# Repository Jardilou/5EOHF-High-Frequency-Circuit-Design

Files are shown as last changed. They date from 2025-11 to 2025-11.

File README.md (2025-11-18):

# 5EOHF-High-Frequency-Circuit-Design
The goal of this project is to create a pcb using an ESP32 microcontroller and able to send gps signals via LoRa communication. Two circuits will be fabricated separately, the first one for the microcontroller and the associated modules and the second one for the design of the antenna.

## 1. Project description
The components required for the main pcb assemply are listed in the BOM. Mainly, the modules are :
- GPS : SAM-M8Q-0
- ESP32 S3
- Lora Module RFM95 (868 MHz - without antenna, to be designed)
- Battery Power management 2S – BQ 25798
- USBC charging and programming pin
- SMA for custom antenna (868 MHz)

## 2. Schematic and Printed Circuit Board

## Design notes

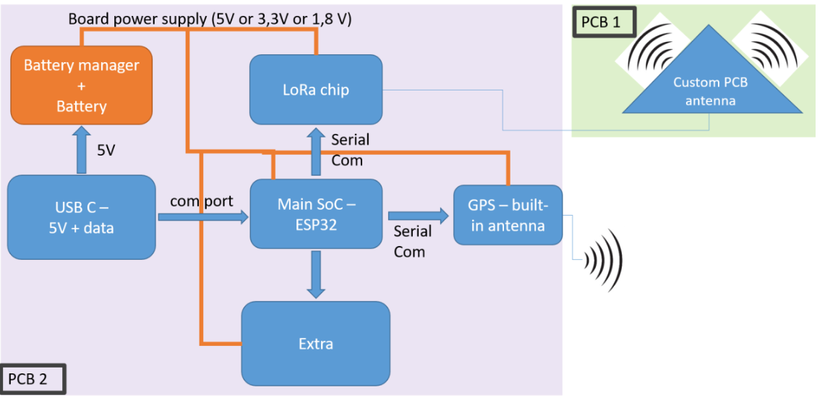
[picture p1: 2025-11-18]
Images/Block_Diagram.png

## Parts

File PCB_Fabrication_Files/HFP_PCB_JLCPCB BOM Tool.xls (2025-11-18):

JLCPCB BOM Tool - BOM Matching
BOM name：HFP_PCB-JLCPCB Assembly Order.xlsx |  |  |  | Download Time：2025-10-25 20:58:56 |  |  |  | * Our matching results are updated in real-time, but stock and prices may change. If it's been over 24 hours, please re-match before placing your order.
PCB Assembled Qty：2 |  |  |  | Est. Total Price：132.1933 (Pre-order parts require a quotation for final pricing.)
Your BOM |  |  |  | Matched Parts |  |  |  |  |  |  | Order Information
Designator | Comment | Footprint | JLCPCB Part # | Matches | Part # | Manufacturer | Footprint | Description | Category | Warning | JLCPCB Part # | Product link | Source | Lib Type | MOQ | Availability | My Parts(JLCPCB Parts) | My Parts(Global sourcing & consigned parts) | Rec. Order Qty | Unit Price ($) | Total Price ($)
680UF;C33;CP_ELEC_8X10 | 680UF;C33;CP_ELEC_8X10 | 680UF;C33;CP_ELEC_8X10 |  | Select by System | VMMD0790J681MV | Ymin | 680UF;C33;CP_ELEC_8X10 | 6.3V 680uF 7.9mm 8mm ±20% SMD,D8xL7.9mm Aluminum Electrolytic Capacitors - SMD ROHS | Aluminum Electrolytic Capacitors - SMD |  | C487009 | https://jlcpcb.com/partdetail/Ymin-VMMD0790J681MV/C487009 | In-stock | Extended | 1 | 8 | 0 | 0 | 2 | 0.2127 | 0.4254
10K;R24,R25,R16,R14;R_0201_0603METRIC | 10K;R24,R25,R16,R14;R_0201_0603METRIC | 10K;R24,R25,R16,R14;R_0201_0603METRIC |  | Unconfirmed | CR0201FH1002G | LIZ Elec | 10K;R24,R25,R16,R14;R_0201_0603METRIC | -55℃~+125℃ 10kΩ 25V 50mW Thick Film Resistor ±1% ±250ppm/℃ 0201 Chip Resistor - Surface Mount ROHS | Chip Resistor - Surface Mount | 1.There may be multiple types of parts, but one type of part has been matched. Please check.; | C100126 | https://jlcpcb.com/partdetail/LIZElec-CR0201FH1002G/C100126 | In-stock | Extended | 1 | 4355 | 0 | 0 | 20 | 0.0008 | 0.016
127K;R21;R_0201_0603METRIC | 127K;R21;R_0201_0603METRIC | 127K;R21;R_0201_0603METRIC |  | Select by System | RC0201FR-07127KL | YAGEO | 127K;R21;R_0201_0603METRIC | -55℃~+125℃ 127kΩ 25V 50mW Thick Film Resistor ±1% ±200ppm/℃ 0201 Chip Resistor - Surface Mount ROHS | Chip Resistor - Surface Mount |  | C138177 | https://jlcpcb.com/partdetail/YAGEO-RC0201FR07127KL/C138177 | In-stock | Extended | 1 | 2456 | 0 | 0 | 20 | 0.0005 | 0.01
6.04K;R20;R_0201_0603METRIC | 6.04K;R20;R_0201_0603METRIC | 6.04K;R20;R_0201_0603METRIC |  | Select by System | 0201WMF6041TEE | UNI-ROYAL(Uniroyal Elec) | 6.04K;R20;R_0201_0603METRIC | -55℃~+155℃ 25V 50mW 6.04kΩ Thick Film Resistor ±1% ±200ppm/℃ 0201 Chip Resistor - Surface Mount ROHS | Chip Resistor - Surface Mount |  | C270341 | https://jlcpcb.com/partdetail/259871-0201WMF6041TEE/C270341 | In-stock | Extended | 1 | 9077 | 0 | 0 | 20 | 0.0008 | 0.016
USB_C_RECEPTACLE_USB2.0_16P;J8;USB_C_RECEPTACLE_HRO_TYPE-C-31-M-12 | USB_C_RECEPTACLE_USB2.0_16P;J8;USB_C_RECEPTACLE_HRO_TYPE-C-31-M-12 | USB_C_RECEPTACLE_USB2.0_16P;J8;USB_C_RECEPTACLE_HRO_TYPE-C-31-M-12 |  | Select by System | TYPE-C-31-M-12 | Korean Hroparts Elec | USB_C_RECEPTACLE_USB2.0_16P;J8;USB_C_RECEPTACLE_HRO_TYPE-C-31-M-12 | 1 16P 5A Female Type-C SMD USB Connectors ROHS | USB Connectors |  | C165948 | https://jlcpcb.com/partdetail/Korean_HropartsElec-TYPE_C_31_M12/C165948 | In-stock | Extended | 1 | 337909 | 0 | 0 | 2 | 0.1694 | 0.3388
47NF;C29,C30;C_0603_1608METRIC | 47NF;C29,C30;C_0603_1608METRIC | 47NF;C29,C30;C_0603_1608METRIC |  | Unconfirmed | CL10B473KB8NNNC | Samsung Electro-Mechanics | 47NF;C29,C30;C_0603_1608METRIC | 47nF 50V X7R ±10% 0603 Multilayer Ceramic Capacitors MLCC - SMD/SMT ROHS | Multilayer Ceramic Capacitors MLCC - SMD/SMT | 1.There may be multiple types of parts, but one type of part has been matched. Please check.; | C1622 | https://jlcpcb.com/partdetail/1974-CL10B473KB8NNNC/C1622 | In-stock | Basic | 1 | 677018 | 0 | 0 | 20 | 0.0053 | 0.106
470;R26,R23;R_0201_0603METRIC | 470;R26,R23;R_0201_0603METRIC | 470;R26,R23;R_0201_0603METRIC |  | Unconfirmed | RTT014700FTH | RALEC | 470;R26,R23;R_0201_0603METRIC | -55℃~+125℃ 25V 470Ω 50mW Thick Film Resistor ±1% ±200ppm/℃ 0201 Chip Resistor - Surface Mount ROHS | Chip Resistor - Surface Mount | 1.There may be multiple types of parts, but one type of part has been matched. Please check.; | C166182 | https://jlcpcb.com/partdetail/RALEC-RTT014700FTH/C166182 | In-stock | Extended | 1 | 9899 | 0 | 0 | 20 | 0.0007 | 0.014
CONN_01X02_SOCKET;J7,J11,J9,J10;JST_EH_B2B-EH-A_1X02_P2.50MM_VERTICAL | CONN_01X02_SOCKET;J7,J11,J9,J10;JST_EH_B2B-EH-A_1X02_P2.50MM_VERTICAL | CONN_01X02_SOCKET;J7,J11,J9,J10;JST_EH_B2B-EH-A_1X02_P2.50MM_VERTICAL |  | Unconfirmed | B2B-EH-A(LF)(SN) | JST | CONN_01X02_SOCKET;J7,J11,J9,J10;JST_EH_B2B-EH-A_1X02_P2.50MM_VERTICAL | -25℃~+85℃ 1 1x2P 2 2.5mm 250V 2P 3.8mm 3A 6mm 7.5mm Brass EH PA66 Through Hole Tin UL94V-0 White Plugin,P=2.5mm Wire To Board Connector ROHS | Wire To Board Connector | 1.There may be multiple types of parts, but one type of part has been matched. Please check.; | C160262 | https://jlcpcb.com/partdetail/JST-B2B_EH_A_LF_SN/C160262 | In-stock | Extended | 1 | 16756 | 0 | 0 | 12 | 0.0377 | 0.4524
CONN_COAXIAL_SMALL;J12;BNC_TECONNECTIVITY_1478204_VERTICAL | CONN_COAXIAL_SMALL;J12;BNC_TECONNECTIVITY_1478204_VERTICAL | CONN_COAXIAL_SMALL;J12;BNC_TECONNECTIVITY_1478204_VERTICAL |  | Select by System | BNC-KF | cntitle | CONN_COAXIAL_SMALL;J12;BNC_TECONNECTIVITY_1478204_VERTICAL | - Coaxial Connectors (RF) ROHS | Coaxial Connectors (RF) |  | C20415781 | https://jlcpcb.com/partdetail/cntitle-BNCKF/C20415781 | In-stock | Extended | 1 | 89 | 0 | 0 | 2 | 1.47 | 2.94
1UH;L3;L_APV_ANR4018 | 1UH;L3;L_APV_ANR4018 | 1UH;L3;L_APV_ANR4018 |  | Select by System | PRS4018-1R0NT | FH (Guangdong Fenghua Advanced Tech) | 1UH;L3;L_APV_ANR4018 | 1uH 2A 39mΩ Magnetic Shielded Inductor ±30% SMD,4x4mm Power Inductors ROHS | Power Inductors |  | C96152 | https://jlcpcb.com/partdetail/97356-PRS40181R0NT/C96152 | In-stock | Extended | 1 | 180 | 0 | 0 | 6 | 0.0456 | 0.2736
0.1UF;C2,C35,C31,C32,C41;C_0402_1005METRIC | 0.1UF;C2,C35,C31,C32,C41;C_0402_1005METRIC | 0.1UF;C2,C35,C31,C32,C41;C_0402_1005METRIC |  | Unconfirmed | CL05B104KO5NNNC | Samsung Electro-Mechanics | 0.1UF;C2,C35,C31,C32,C41;C_0402_1005METRIC | 100nF 16V X7R ±10% 0402 Multilayer Ceramic Capacitors MLCC - SMD/SMT ROHS | Multilayer Ceramic Capacitors MLCC - SMD/SMT | 1.There may be multiple types of parts, but one type of part has been matched. Please check.; | C1525 | https://jlcpcb.com/partdetail/1877-CL05B104KO5NNNC/C1525 | In-stock | Basic | 1 | 16856069 | 0 | 0 | 20 | 0.0012 | 0.024
5K1;R17,R18;R_0201_0603METRIC | 5K1;R17,R18;R_0201_0603METRIC | 5K1;R17,R18;R_0201_0603METRIC |  | Unconfirmed | CR0201FH5101G | LIZ Elec | 5K1;R17,R18;R_0201_0603METRIC | -55℃~+125℃ 25V 5.1kΩ 50mW Thick Film Resistor ±1% ±250ppm/℃ 0201 Chip Resistor - Surface Mount ROHS | Chip Resistor - Surface Mount | 1.There may be multiple types of parts, but one type of part has been matched. Please check.; | C100142 | https://jlcpcb.com/partdetail/LIZElec-CR0201FH5101G/C100142 | In-stock | Extended | 1 | 2062 | 0 | 0 | 20 | 0.0007 | 0.014
10UF;C34,C45,C50,C44,C42,C43,C46,C49,C39,C37,C48,C40,C47,C51;C_1206_3216METRIC | 10UF;C34,C45,C50,C44,C42,C43,C46,C49,C39,C37,C48,C40,C47,C51;C_1206_3216METRIC | 10UF;C34,C45,C50,C44,C42,C43,C46,C49,C39,C37,C48,C40,C47,C51;C_1206_3216METRIC |  | Unconfirmed | CL31A106KOHNNNE | Samsung Electro-Mechanics | 10UF;C34,C45,C50,C44,C42,C43,C46,C49,C39,C37,C48,C40,C47,C51;C_1206_3216METRIC | 10uF 16V X5R ±10% 1206 Multilayer Ceramic Capacitors MLCC - SMD/SMT ROHS | Multilayer Ceramic Capacitors MLCC - SMD/SMT | 1.There may be multiple types of parts, but one type of part has been matched. Please check.; | C1849 | https://jlcpcb.com/partdetail/2201-CL31A106KOHNNNE/C1849 | In-stock | Extended | 1 | 143159 | 0 | 0 | 36 | 0.0272 | 0.9792
100;R19;R_0201_0603METRIC | 100;R19;R_0201_0603METRIC | 100;R19;R_0201_0603METRIC |  | Select by System | RC0201FR-07100RL | YAGEO | 100;R19;R_0201_0603METRIC | -55℃~+125℃ 100Ω 25V 50mW Thick Film Resistor ±1% ±200ppm/℃ 0201 Chip Resistor - Surface Mount ROHS | Chip Resistor - Surface Mount |  | C77623 | https://jlcpcb.com/partdetail/YAGEO-RC0201FR07100RL/C77623 | In-stock | Extended | 1 | 133970 | 0 | 0 | 20 | 0.0008 | 0.016
33UH;L4;L_APV_ANR8040 | 33UH;L4;L_APV_ANR8040 | 33UH;L4;L_APV_ANR8040 |  | Select by System | FNR8040S330MT | cjiang (Changjiang Microelectronics Tech) | 33UH;L4;L_APV_ANR8040 | 126mΩ 2.4A 2A 33uH Magnetic Shielded Inductor ±20% SMD,8x8mm Power Inductors ROHS | Power Inductors |  | C168133 | https://jlcpcb.com/partdetail/179516-FNR8040S330MT/C168133 | In-stock | Extended | 1 | 6888 | 0 | 0 | 5 | 0.1023 | 0.5115
1NF;C36;C_0402_1005METRIC | 1NF;C36;C_0402_1005METRIC | 1NF;C36;C_0402_1005METRIC |  | Select by System | 0402B102K500NT | FH (Guangdong Fenghua Advanced Tech) | 1NF;C36;C_0402_1005METRIC | 1nF 50V X7R ±10% 0402 Multilayer Ceramic Capacitors MLCC - SMD/SMT ROHS | Multilayer Ceramic Capacitors MLCC - SMD/SMT |  | C1523 | https://jlcpcb.com/partdetail/1875-0402B102K500NT/C1523 | In-stock | Basic | 1 | 1460783 | 0 | 0 | 20 | 0.0011 | 0.022
LM2596S-3.3;U9;TO-263-5_TABPIN3 | LM2596S-3.3;U9;TO-263-5_TABPIN3 | LM2596S-3.3;U9;TO-263-5_TABPIN3 |  | Select by System | LM2596S-3.3 | GR | LM2596S-3.3;U9;TO-263-5_TABPIN3 | -20℃~+70℃ 1 170kHz 2mA 3.3V 3A 4.5V~40V Buck Buck Built-In Fixed No TO-263-5L DC-DC Converters ROHS | DC-DC Converters |  | C19631822 | https://jlcpcb.com/partdetail/GR-LM2596S_33/C19631822 | In-stock | Extended | 1 | 4577 | 0 | 0 | 2 | 0.252 | 0.504
100K;R22;R_0201_0603METRIC | 100K;R22;R_0201_0603METRIC | 100K;R22;R_0201_0603METRIC |  | Select by System | CR0201FH1003G | LIZ Elec | 100K;R22;R_0201_0603METRIC | -55℃~+125℃ 100kΩ 25V 50mW Thick Film Resistor ±1% ±250ppm/℃ 0201 Chip Resistor - Surface Mount ROHS | Chip Resistor - Surface Mount |  | C100127 | https://jlcpcb.com/partdetail/LIZElec-CR0201FH1003G/C100127 | In-stock | Extended | 1 | 7239 | 0 | 0 | 20 | 0.0008 | 0.016
AMS1117-3.3;U10;SOT-223-3_TABPIN2 | AMS1117-3.3;U10;SOT-223-3_TABPIN2 | AMS1117-3.3;U10;SOT-223-3_TABPIN2 |  | Unconfirmed | AMS1117-3.3 | Advanced Monolithic Systems | AMS1117-3.3;U10;SOT-223-3_TABPIN2 | -40℃~+125℃ 0.003%Vout 1 1.1V@(800mA) 16V 1A 3.3V 5mA 72dB@(120Hz) Fixed Over Current Protection Positive SOT-223 Voltage Regulators - Linear, Low Drop Out (LDO) Regulators ROHS | Voltage Regulators - Linear, Low Drop Out (LDO) Regulators | 1.The comment (AMS1117-3.3) of this part does not match the one (AMS1117-3.3;U10;SOT-223-3_TABPIN2) provided in your BOM. Please confirm; | C6186 | https://jlcpcb.com/partdetail/Advanced_MonolithicSystems-AMS1117_33/C6186 | In-stock | Basic | 1 | 1320981 | 0 | 0 | 2 | 0.1639 | 0.3278
1N5820;D2;D_DO-201AD_P15.24MM_HORIZONTAL | 1N5820;D2;D_DO-201AD_P15.24MM_HORIZONTAL | 1N5820;D2;D_DO-201AD_P15.24MM_HORIZONTAL |  | Select by Customer | 1N5820RLG | onsemi | 1N5820;D2;D_DO-201AD_P15.24MM_HORIZONTAL | 20V 2mA@20V 3A 850mV@9.3A DO-201AD Schottky Diodes ROHS | Schottky Diodes |  | C900156 | https://jlcpcb.com/partdetail/onsemi-1N5820RLG/C900156 | Pre-order | Extended | 25 | 0 | 0 | 0 | 25 | 0.3515 | 8.7875
BQ25798RQMR;U8;IC_BQ25798RQMR | BQ25798RQMR;U8;IC_BQ25798RQMR | BQ25798RQMR;U8;IC_BQ25798RQMR |  | Select by System | BQ25798RQMR | Texas Instruments | BQ25798RQMR;U8;IC_BQ25798RQMR | -40℃~+85℃ 17uA 1~4 3.6V~24V 5A Charging IC I2C Lithium Battery Support QFN-29(4x4) Battery Management ROHS | Battery Management |  | C2876593 | https://jlcpcb.com/partdetail/TexasInstruments-BQ25798RQMR/C2876593 | Pre-order | Extended | 4 | 0 | 0 | 0 | 4 | 2.2725 | 9.09
1M;R15;R_0201_0603METRIC | 1M;R15;R_0201_0603METRIC | 1M;R15;R_0201_0603METRIC |  | Select by System | CR0201FH1004G | LIZ Elec | 1M;R15;R_0201_0603METRIC | -55℃~+125℃ 1MΩ 25V 50mW Thick Film Resistor ±1% ±250ppm/℃ 0201 Chip Resistor - Surface Mount ROHS | Chip Resistor - Surface Mount |  | C100128 | https://jlcpcb.com/partdetail/LIZElec-CR0201FH1004G/C100128 | Pre-order | Extended | 10000 | 5 | 0 | 0 | 10000 | 0.0006 | 6
4.7UF;C38;C_0805_2012METRIC | 4.7UF;C38;C_0805_2012METRIC | 4.7UF;C38;C_0805_2012METRIC |  | Select by System | C0805C475K3PAC7800 | KEMET | 4.7UF;C38;C_0805_2012METRIC | 25V 4.7uF X5R ±10% 0805 Multilayer Ceramic Capacitors MLCC - SMD/SMT ROHS | Multilayer Ceramic Capacitors MLCC - SMD/SMT |  | C141036 | https://jlcpcb.com/partdetail/KEMET-C0805C475K3PAC7800/C141036 | Pre-order | Extended | 165 | 0 | 0 | 0 | 165 | 0.0521 | 8.5965
RFM95W-868S2;U13;HOPERF_RFM9XW_SMD | RFM95W-868S2;U13;HOPERF_RFM9XW_SMD | RFM95W-868S2;U13;HOPERF_RFM9XW_SMD |  | Select by System | RFM95W-868S2R | HOPE MICROELECTRONICS | RFM95W-868S2;U13;HOPERF_RFM9XW_SMD | LCC-16_16X16X2.0P New Arrivals ROHS | New Arrivals |  | C5440766 | https://jlcpcb.com/partdetail/HOPEMICROELECTRONICS-RFM95W868S2R/C5440766 | Pre-order | Extended | 456 | 0 | 0 | 0 | 456 | 0.0188 | 8.5728
ESP32-S3-WROOM-2;U2;ESP32-S3-WROOM-2 | ESP32-S3-WROOM-2;U2;ESP32-S3-WROOM-2 | ESP32-S3-WROOM-2;U2;ESP32-S3-WROOM-2 |  | Select by System | ESP32-S3-WROOM-2-N32R8V | JLCPCB Assembly | ESP32-S3-WROOM-2;U2;ESP32-S3-WROOM-2 | LCC+LGA SMT ROHS | SMT |  | C9900017856 | https://jlcpcb.com/partdetail/3524184-ESP32_S3_WROOM_2N32R8V/C9900017856 | Pre-order | Extended | 456 | 0 | 0 | 0 | 456 | 0.0188 | 8.5728
SAM-M8Q;U11;UBLOX_SAM-M8Q | SAM-M8Q;U11;UBLOX_SAM-M8Q | SAM-M8Q;U11;UBLOX_SAM-M8Q |  | Select by System | SAM-M8Q-0 | U-BLOX | SAM-M8Q;U11;UBLOX_SAM-M8Q | SMD-20P,15x15mm GNSS Modules ROHS | GNSS Modules |  | C5447387 | https://jlcpcb.com/partdetail/UBLOX-SAM_M8Q0/C5447387 | Pre-order | Extended | 1 | 0 | 0 | 0 | 2 | 37.7835 | 75.567
ESP32-S3-DEVKITC-1-N8R2;U14;XCVR_ESP32-S3-DEVKITC-1-N8R2 | ESP32-S3-DEVKITC-1-N8R2;U14;XCVR_ESP32-S3-DEVKITC-1-N8R2 | ESP32-S3-DEVKITC-1-N8R2;U14;XCVR_ESP32-S3-DEVKITC-1-N8R2 |  | No matches |  | No Part Selected
TESTPOINT;TP20,TP26,TP16,TP28,TP23,TP22,TP19,TP29,TP30,TP27,TP25,TP17,TP24,TP18,TP21;TESTPOINT_KEYSTONE_5005-5009_COMPACT | TESTPOINT;TP20,TP26,TP16,TP28,TP23,TP22,TP19,TP29,TP30,TP27,TP25,TP17,TP24,TP18,TP21;TESTPOINT_KEYSTONE_5005-5009_COMPACT | TESTPOINT;TP20,TP26,TP16,TP28,TP23,TP22,TP19,TP29,TP30,TP27,TP25,TP17,TP24,TP18,TP21;TESTPOINT_KEYSTONE_5005-5009_COMPACT |  | No matches |  | No Part Selected
COMMENT;DESIGNATOR;FOOTPRINT | COMMENT;DESIGNATOR;FOOTPRINT | COMMENT;DESIGNATOR;FOOTPRINT |  | No matches |  | No Part Selected

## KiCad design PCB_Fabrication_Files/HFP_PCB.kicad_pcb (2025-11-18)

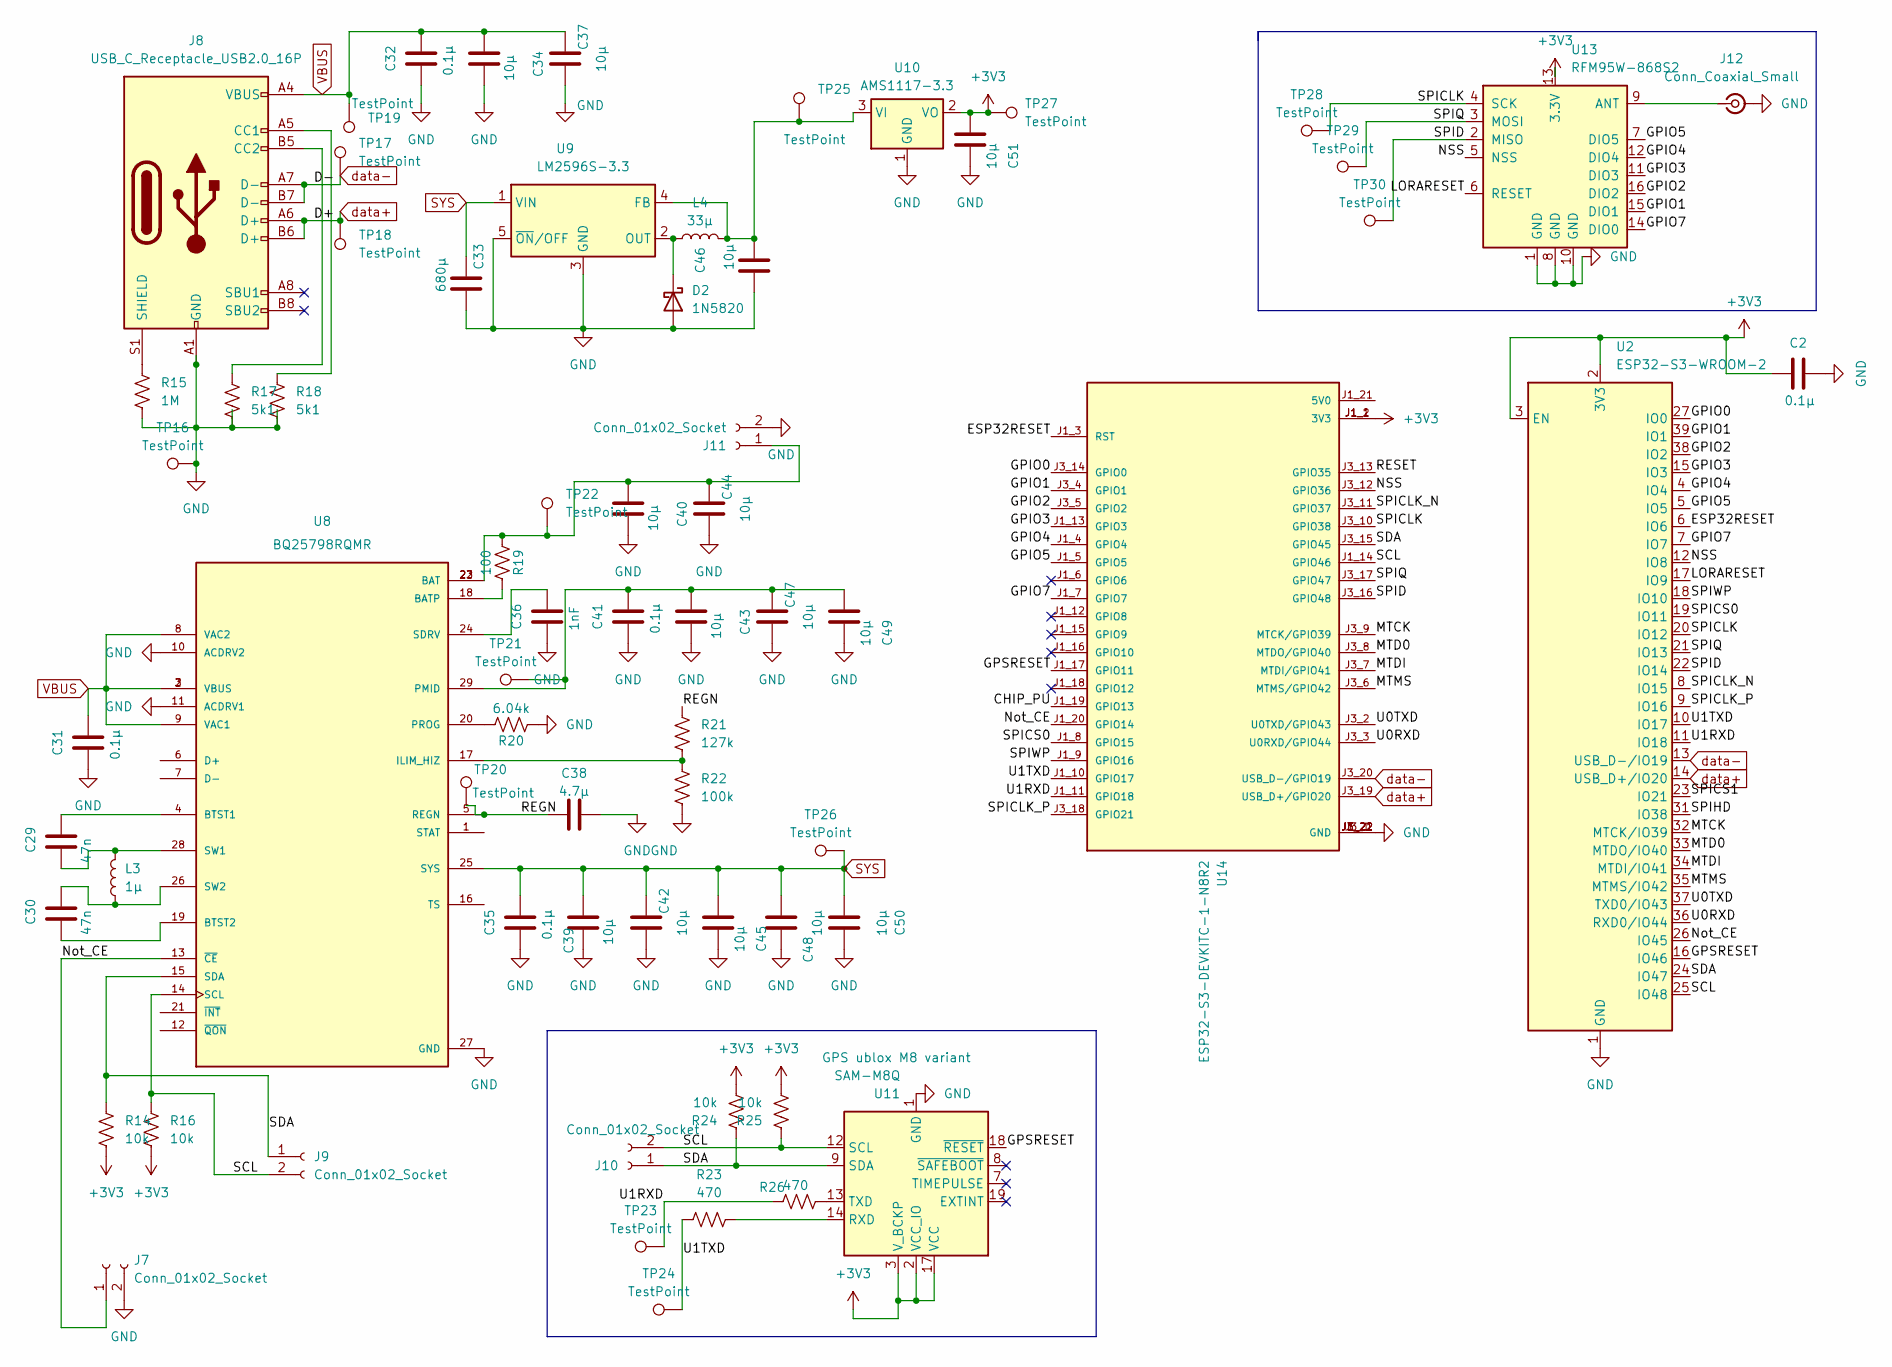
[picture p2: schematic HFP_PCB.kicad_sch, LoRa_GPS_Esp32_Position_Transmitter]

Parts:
C2, C31, C32, C35, C41: 0.1µ; C_0402_1005Metric
C29, C30: 47n; C_0603_1608Metric
C33: 680µ; CP_Elec_8x10
C34, C37, C39, C40, C42, C43, C44, C45, C46, C47, C48, C49, C50, C51: 10µ; C_1206_3216Metric
C36: 1nF; C_0402_1005Metric
C38: 4.7µ; C_0805_2012Metric
D2: 1N5820; D_DO-201AD_P15.24mm_Horizontal
J7, J9, J10, J11: Conn_01x02_Socket; JST_EH_B2B-EH-A_1x02_P2.50mm_Vertical
J8: USB_C_Receptacle_USB2.0_16P; USB_C_Receptacle_HRO_TYPE-C-31-M-12
J12: Conn_Coaxial_Small; BNC_TEConnectivity_1478204_Vertical
L3: 1µ; L_APV_ANR4018
L4: 33µ; L_APV_ANR8040
R14, R16, R24, R25: 10k; R_0201_0603Metric
R15: 1M; R_0201_0603Metric
R17, R18: 5k1; R_0201_0603Metric
R19: 100; R_0201_0603Metric
R20: 6.04k; R_0201_0603Metric
R21: 127k; R_0201_0603Metric
R22: 100k; R_0201_0603Metric
R23, R26: 470; R_0201_0603Metric
TP16, TP17, TP18, TP19, TP20, TP21, TP22, TP23, TP24, TP25, TP26, TP27, TP28, TP29, TP30: TestPoint; TestPoint_Keystone_5005-5009_Compact
U2: ESP32-S3-WROOM-2
U8: BQ25798RQMR; IC_BQ25798RQMR; PARTREV B
U9: LM2596S-3.3; TO-263-5_TabPin3
U10: AMS1117-3.3; SOT-223-3_TabPin2
U11: SAM-M8Q; ublox_SAM-M8Q
U13: RFM95W-868S2; HOPERF_RFM9XW_SMD
U14: ESP32-S3-DEVKITC-1-N8R2; XCVR_ESP32-S3-DEVKITC-1-N8R2; PARTREV V1

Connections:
+3V3: C2.1, C51.1, R14.1, R16.1, R24.1, R25.1, TP27.1, U2.2 (3V3), U2.3 (EN), U10.2 (VO), U11.2 (VCC_IO), U11.3 (V_BCKP), U11.17 (VCC), U13.13 (3.3V), U14.J1_1 (3V3), U14.J1_2 (3V3)
/CHIP_PU: U14.J1_19 (GPIO13)
/ESP32RESET: U2.6 (IO6), U14.J1_3 (RST)
/GPIO0: U2.27 (IO0), U14.J3_14 (GPIO0)
/GPIO1: U2.39 (IO1), U13.15 (DIO1), U14.J3_4 (GPIO1)
/GPIO2: U2.38 (IO2), U13.16 (DIO2), U14.J3_5 (GPIO2)
/GPIO3: U2.15 (IO3), U13.11 (DIO3), U14.J1_13 (GPIO3)
/GPIO4: U2.4 (IO4), U13.12 (DIO4), U14.J1_4 (GPIO4)
/GPIO5: U2.5 (IO5), U13.7 (DIO5), U14.J1_5 (GPIO5)
/GPIO7: U2.7 (IO7), U13.14 (DIO0), U14.J1_7 (GPIO7)
/GPSRESET: U2.16 (IO46), U11.18 (~RESET), U14.J1_17 (GPIO11)
/LORARESET: U2.17 (IO9), U13.6 (RESET)
/MTCK: U2.32 (MTCK/IO39), U14.J3_9 (MTCK/GPIO39)
/MTD0: U2.33 (MTDO/IO40), U14.J3_8 (MTDO/GPIO40)
/MTDI: U2.34 (MTDI/IO41), U14.J3_7 (MTDI/GPIO41)
/MTMS: U2.35 (MTMS/IO42), U14.J3_6 (MTMS/GPIO42)
/NSS: U2.12 (IO8), U13.5 (NSS), U14.J3_12 (GPIO36)
/Not_CE: J7.1, U2.26 (IO45), U8.13 (~CE), U14.J1_20 (GPIO14)
/REGN: C38.1, R21.1, TP20.1, U8.5 (REGN)
/RESET: U14.J3_13 (GPIO35)
/SCL: J9.2, J10.2, R16.2, R25.2, U2.25 (IO48), U8.14 (SCL), U11.12 (SCL), U14.J1_14 (GPIO46)
/SDA: J9.1, J10.1, R14.2, R24.2, U2.24 (IO47), U8.15 (SDA), U11.9 (SDA), U14.J3_15 (GPIO45)
/SPICLK: TP28.1, U2.20 (IO12), U13.4 (SCK), U14.J3_10 (GPIO38)
/SPICLK_N: U2.8 (IO15), U14.J3_11 (GPIO37)
/SPICLK_P: U2.9 (IO16), U14.J3_18 (GPIO21)
/SPICS0: U2.19 (IO11), U14.J1_8 (GPIO15)
/SPICS1: U2.23 (IO21)
/SPID: TP30.1, U2.22 (IO14), U13.2 (MISO), U14.J3_16 (GPIO48)
/SPIHD: U2.31 (IO38)
/SPIQ: TP29.1, U2.21 (IO13), U13.3 (MOSI), U14.J3_17 (GPIO47)
/SPIWP: U2.18 (IO10), U14.J1_9 (GPIO16)
/U0RXD: U2.36 (RXD0/IO44), U14.J3_3 (U0RXD/GPIO44)
/U0TXD: U2.37 (TXD0/IO43), U14.J3_2 (U0TXD/GPIO43)
/U1RXD: R26.1, TP23.1, U2.11 (IO18), U14.J1_11 (GPIO18)
/U1TXD: R23.1, TP24.1, U2.10 (IO17), U14.J1_10 (GPIO17)
GND: C2.2, C31.2, C32.2, C33.1, C34.2, C35.2, C36.2, C37.2, C38.2, C39.2, C40.2, C41.2, C42.2, C43.2, C44.2, C45.2, C46.1, C47.2, C48.2, C49.2, C50.2, C51.2, D2.2 (A), J7.2, J8.A1 (GND), J8.A12 (GND), J8.B1 (GND), J8.B12 (GND), J11.2, J12.2 (Ext), R15.1, R17.1, R18.1, R20.1, R22.2, TP16.1, U2.1 (GND), U2.40 (GND), U2.41 (GND), U8.10 (ACDRV2), U8.11 (ACDRV1), U8.27 (GND), U9.3 (GND), U9.5 (~ON/OFF), U10.1 (GND), U11.1 (GND), U11.4 (GND), U11.5 (GND), U11.6 (GND), U11.10 (GND), U11.11 (GND), U11.15 (GND), U11.16 (GND), U11.20 (GND), U13.1 (GND), U13.8 (GND), U13.10 (GND), U14.J1_22 (GND), U14.J3_1 (GND), U14.J3_21 (GND), U14.J3_22 (GND)
unnamed: D2.1 (K), L4.1, U9.2 (OUT)
unnamed: J8.A5 (CC1), R18.2
unnamed: J8.B5 (CC2), R17.2
unnamed: J8.S1 (SHIELD), R15.2
unnamed: C40.1, C44.1, J11.1, R19.1, TP22.1, U8.22 (BAT), U8.23 (BAT)
unnamed: J12.1 (In), U13.9 (ANT)
unnamed: R19.2, U8.18 (BATP)
unnamed: C29.1, U8.4 (BTST1)
unnamed: C30.2, U8.19 (BTST2)
unnamed: R21.2, R22.1, U8.17 (ILIM_HIZ)
unnamed: C41.1, C43.1, C47.1, C49.1, TP21.1, U8.29 (PMID)
unnamed: R20.2, U8.20 (PROG)
unnamed: C36.1, U8.24 (SDRV)
unnamed: C29.2, L3.2, U8.28 (SW1)
unnamed: C30.1, L3.1, U8.26 (SW2)
unnamed: C46.2, L4.2, TP25.1, U9.4 (FB), U10.3 (VI)
unnamed: R23.2, U11.14 (RXD)
unnamed: R26.2, U11.13 (TXD)
SYS: C33.2, C35.1, C39.1, C42.1, C45.1, C48.1, C50.1, TP26.1, U8.25 (SYS), U9.1 (VIN)
VBUS: C31.1, C32.1, C34.1, C37.1, J8.A4 (VBUS), J8.A9 (VBUS), J8.B4 (VBUS), J8.B9 (VBUS), TP19.1, U8.2 (VBUS), U8.3 (VBUS), U8.8 (VAC2), U8.9 (VAC1)
data+: J8.A6 (D+), J8.B6 (D+), TP18.1, U2.14 (USB_D+/IO20), U14.J3_19 (USB_D+/GPIO20)
data-: J8.A7 (D-), J8.B7 (D-), TP17.1, U2.13 (USB_D-/IO19), U14.J3_20 (USB_D-/GPIO19)

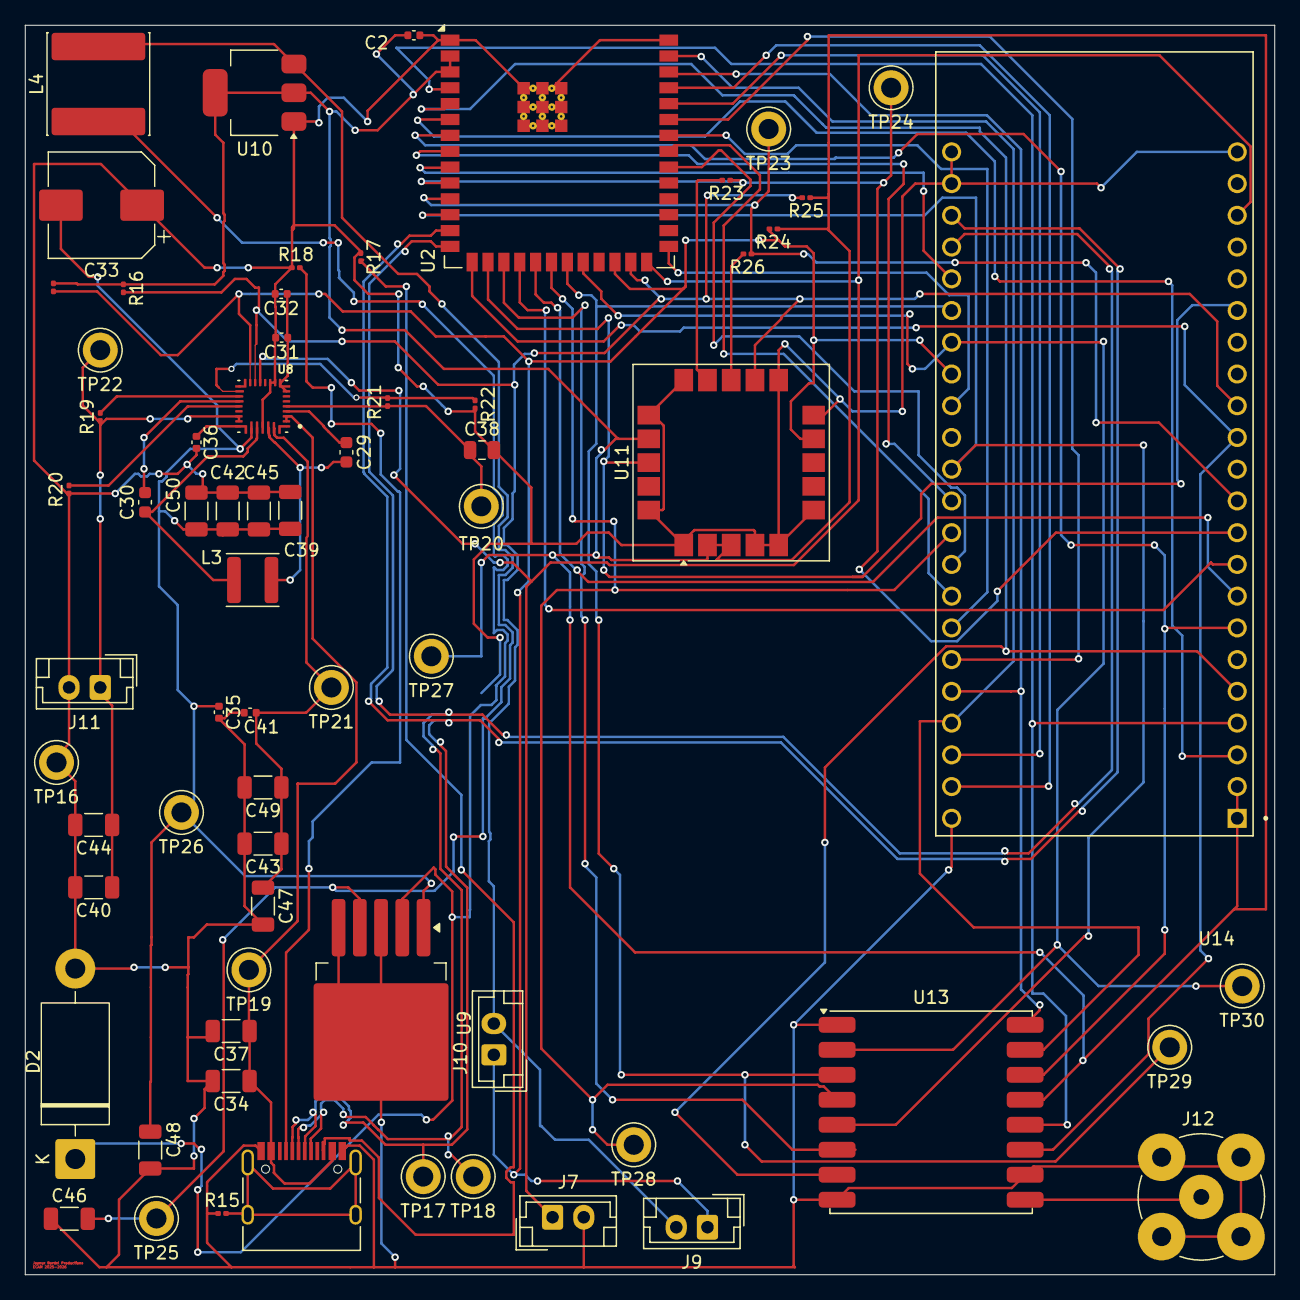
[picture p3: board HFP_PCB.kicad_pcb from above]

Board: 2 copper layers, 100.0 x 100.0 mm, 68 parts (1 on the bottom side), 54 nets.

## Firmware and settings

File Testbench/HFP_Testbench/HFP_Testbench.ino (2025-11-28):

/* 
  ESP32 Unit Test Suite
  - ESP32 basic checks: boot, GPIO toggle
  - WiFi: scan and simple TCP ping attempt (scan only; no credentials)
  - BLE: advertise + passive scan
  - SAM-M8Q: UART NMEA reader + I2C presence probe (addr 0x42)
  - RFM95: SPI RegVersion read, Reset cycle, optional LoRa transmit (if "LoRa" library is installed)
  - Serial output at 115200 for results
  IMPORTANT: Many ESP32 boards reserve GPIO6..GPIO11 for flash/PSRAM. Using GPIO6/GPIO7 may break the module.
  We should adjust pins if we encounter boot issues!
*/

#include <Arduino.h>
#include <Wire.h>
#include <WiFi.h>
#include <BLEDevice.h>
#include <BLEUtils.h>
#include <BLEServer.h>
#include <SPI.h>

// Optional LoRa library: uncomment if you have the Sandeep Mistry LoRa library installed
// #include <LoRa.h>

///// USER PIN CONFIG (from your message) /////
const int PIN_RFM95_SCK  = 33; // SCK
const int PIN_RFM95_SPIQ = 34; // SPIQ (may be DIO/IRQ depending on your board)
const int PIN_RFM95_SPID = 35; // SPID (MISO/MOSI naming ambiguous; treat as MISO here)
const int PIN_RFM95_NSS  = 6;  // NSS (WARNING: GPIO6 is sometimes reserved for flash)
const int PIN_RFM95_RESET= 7;  // RESET (WARNING: GPIO7 may be reserved)
const int PIN_RFM95_DIO0 = PIN_RFM95_SPIQ; // fallback: if SPIQ is DIO0/IRQ, used for LoRa library

const int GPS_UART_TX = 17; // U1TXD (ESP32 -> GPS)
const int GPS_UART_RX = 18; // U1RXD (GPS -> ESP32)
const int GPS_I2C_SDA = 51; // GPIO45
const int GPS_I2C_SCL = 52; // GPIO46
const uint8_t GPS_I2C_ADDR = 0x42; // typical UBX I2C address (0x42)

const int LED_TEST_PIN = 2; // on-board LED or any test pin
const int GPIO_TEST_PINS[] = {2, 4, 12}; // extra pins toggled during GPIO test
const size_t N_GPIO_TEST_PINS = sizeof(GPIO_TEST_PINS)/sizeof(GPIO_TEST_PINS[0]);

HardwareSerial GPSu(1); // use UART1 for GPS (pins 17 TX, 18 RX)

SPIClass hspi(HSPI); // we'll bind HSPI to custom pins

// Helper timing
unsigned long nowMs() { return millis(); }

/////////////////////////
// Test helpers
/////////////////////////

void printHeader(const char* title) {
  Serial.println();
  Serial.print("=== ");
  Serial.print(title);
  Serial.println(" ===");
}

void pauseMs(unsigned long ms) {
  unsigned long t = nowMs();
  while (nowMs() - t < ms) { yield(); }
}

/////////////////////////
// ESP32: power/boot / basic tests
/////////////////////////

void test_boot_and_power() {
  printHeader("ESP32 Boot & Power Test");
  Serial.printf("Boot time millis: %lu\n", nowMs());
  // Basic sanity: check Vcc reading (if ADC on board measures it) - optional
  Serial.println("Note: measure 3.3V rail externally with DVM/oscilloscope under load for full power test.");
  Serial.println("Result: BOOT OK (if you see this message and no brownout resets).");
}

void test_gpio() {
  printHeader("GPIO Digital IO Test");
  Serial.println("Toggling GPIO test pins and reading them back where possible.");
  for (size_t i = 0; i < N_GPIO_TEST_PINS; ++i) {
    int p = GPIO_TEST_PINS[i];
    pinMode(p, OUTPUT);
    digitalWrite(p, LOW);
  }
  pauseMs(100);
  for (size_t i = 0; i < N_GPIO_TEST_PINS; ++i) {
    int p = GPIO_TEST_PINS[i];
    Serial.printf("Toggling pin %d -> HIGH\n", p);
    digitalWrite(p, HIGH);
    pauseMs(200);
    // If you have a multimeter or scope probe, verify the pin shows 3.3V
  }
  pauseMs(200);
  for (size_t i = 0; i < N_GPIO_TEST_PINS; ++i) {
    digitalWrite(GPIO_TEST_PINS[i], LOW);
  }
  Serial.println("GPIO toggle done. Observe with scope/logic analyzer to confirm.");
}

/////////////////////////
// WiFi tests
/////////////////////////

void test_wifi_scan() {
  printHeader("WiFi Scan Test");
  Serial.println("Starting WiFi in STA mode and scanning for networks...");
  WiFi.mode(WIFI_STA);
  WiFi.disconnect();
  pauseMs(100);
  int n = WiFi.scanNetworks();
  Serial.printf("Found %d networks:\n", n);
  for (int i = 0; i < n; ++i) {
    Serial.printf("  %d: %s (RSSI %d dBm) Channel %d, Encryption: %s\n",
                  i, WiFi.SSID(i).c_str(), WiFi.RSSI(i), WiFi.channel(i),
                  WiFi.encryptionType(i) == WIFI_AUTH_OPEN ? "OPEN" : "SECURE");
  }
  if (n == 0) Serial.println("No networks found (check antenna / board).");
  WiFi.scanDelete();
}

void test_wifi_softap() {
  printHeader("WiFi SoftAP Test");
  Serial.println("Bringing up SoftAP (no password) to verify WiFi stack and antenna.");
  WiFi.mode(WIFI_AP);
  bool ok = WiFi.softAP("ESP32_UnitTest_AP");
  Serial.printf("softAP start: %s\n", ok ? "OK" : "FAILED");
  IPAddress ip = WiFi.softAPIP();
  Serial.printf("SoftAP IP: %s\n", ip.toString().c_str());
  WiFi.softAPdisconnect(true);
  WiFi.mode(WIFI_OFF);
}

/////////////////////////
// BLE tests
/////////////////////////

void test_ble_advertise_and_scan() {
  printHeader("BLE Advertise & Scan Test");
  Serial.println("Initializing BLE device...");
  BLEDevice::init("ESP32_UnitTest");
  BLEServer *pServer = BLEDevice::createServer();
  Serial.println("Starting advertise (30s) and local passive scan for devices...");
  BLEAdvertising *pAdvertising = BLEDevice::getAdvertising();
  pAdvertising->start();
  // Passive scan using NimBLE/other libs is more involved; here we show advertise success:
  Serial.println("BLE advertiser started. Use a phone to confirm presence named 'ESP32_UnitTest'.");
  pauseMs(5000);
  pAdvertising->stop();
  Serial.println("BLE advertise stopped.");
}

/////////////////////////
// SAM-M8Q GPS tests
/////////////////////////

void test_gps_uart() {
  printHeader("GPS UART Test (NMEA)");
  Serial.println("Opening UART1 for GPS at 9600/UBX default (try 9600 and 38400 if needed)...");
  GPSu.begin(9600, SERIAL_8N1, GPS_UART_RX, GPS_UART_TX); // rx, tx
  unsigned long tstart = nowMs();
  Serial.println("Listening for NMEA sentences for 6 seconds...");
  String buffer;
  while (nowMs() - tstart < 6000UL) {
    while (GPSu.available()) {
      char c = GPSu.read();
      buffer += c;
      if (c == '\n') {
        // Print complete line
        buffer.trim();
        if (buffer.length() > 0) {
          Serial.printf("GPS UART: %s\n", buffer.c_str());
        }
        buffer = "";
      }
    }
    yield();
  }
  Serial.println("End of UART listen. If you saw GGA/RMC/NMEA lines then UART is working and GPS has clear view.");
}

void test_gps_i2c_probe() {
  printHeader("GPS I2C Presence Probe (address 0x42)");
  // Use Wire with custom pins:
  // On ESP32, Wire.begin(SDA, SCL) with integer pins above 21 works if board supports them
  Wire.end();
  Wire.begin(GPS_I2C_SDA, GPS_I2C_SCL);
  pauseMs(50);
  Serial.print("Scanning I2C for device 0x42... ");
  Wire.beginTransmission(GPS_I2C_ADDR);
  uint8_t err = Wire.endTransmission();
  if (err == 0) {
    Serial.println("OK: Device responded at 0x42 (likely SAM-M8Q UBX I2C).");
  } else {
    Serial.printf("NO RESPONSE (err=%d). If GPS is using I2C, check wiring/power and that GPS supports I2C.\n", err);
  }
  // Optionally request a few bytes
  Wire.requestFrom(GPS_I2C_ADDR, (uint8_t)6);
  if (Wire.available()) {
    Serial.print("I2C read bytes: ");
    while (Wire.available()) {
      Serial.printf("0x%02X ", Wire.read());
    }
    Serial.println();
  } else {
    Serial.println("No readable bytes from I2C device (or device requires UBX framing).");
  }
}

/////////////////////////
// RFM95 (SX127x family) SPI checks
/////////////////////////

// SX1276/77/78/79 RegVersion is at 0x42 and commonly returns 0x12 for known silicon.
// SPI protocol: MSB=1 for write, MSB=0 for read (i.e., readAddr = addr & 0x7F)
uint8_t rfm95_read_reg(uint8_t addr) {
  uint8_t readAddr = addr & 0x7F;
  digitalWrite(PIN_RFM95_NSS, LOW);
  uint8_t resp = hspi.transfer(readAddr);
  resp = hspi.transfer(0x00);
  digitalWrite(PIN_RFM95_NSS, HIGH);
  return resp;
}

void rfm95_write_reg(uint8_t addr, uint8_t value) {
  uint8_t writeAddr = addr | 0x80; // set MSB for write
  digitalWrite(PIN_RFM95_NSS, LOW);
  hspi.transfer(writeAddr);
  hspi.transfer(value);
  digitalWrite(PIN_RFM95_NSS, HIGH);
}

void test_rfm95_spi_basic() {
  printHeader("RFM95 SPI Basic Test");
  Serial.println("Configuring HSPI with user pins and toggling reset.");
  // configure HSPI pins
  // NOTE: If your board uses GPIO6/GPIO7 for flash, this will break. Consider changing NSS/RESET.
  hspi.begin(PIN_RFM95_SCK, PIN_RFM95_SPID, /*MOSI*/ PIN_RFM95_SCK, /*SCLK duplicated*/ PIN_RFM95_SCK); 
  // The above line won't be perfect for some boards — we still set pinMode for NSS
  pinMode(PIN_RFM95_NSS, OUTPUT);
  digitalWrite(PIN_RFM95_NSS, HIGH);
  pinMode(PIN_RFM95_RESET, OUTPUT);
  // reset pulse
  digitalWrite(PIN_RFM95_RESET, LOW);
  pauseMs(10);
  digitalWrite(PIN_RFM95_RESET, HIGH);
  pauseMs(10);

  Serial.println("Reading RegVersion (0x42)...");
  uint8_t ver = rfm95_read_reg(0x42);
  Serial.printf("RegVersion read: 0x%02X\n", ver);
  if (ver == 0x12) {
    Serial.println("RegVersion matched expected SX1276/7/8/9 silicon (0x12). SPI appears functional.");
  } else {
    Serial.println("Unexpected RegVersion. This may be okay if different silicon; if 0x00 or 0xFF check wiring and flash-pin conflicts.");
  }

  Serial.println("Toggling NSS and RESET a few times to confirm control lines.");
  for (int i=0;i<3;i++){
    digitalWrite(PIN_RFM95_NSS, LOW);
    pauseMs(50);
    digitalWrite(PIN_RFM95_NSS, HIGH);
    pauseMs(50);
    digitalWrite(PIN_RFM95_RESET, LOW);
    pauseMs(20);
    digitalWrite(PIN_RFM95_RESET, HIGH);
    pauseMs(200);
  }
  Serial.println("RFM95 SPI basic checks done.");
}

void test_rfm95_sendpackets_if_lora_lib() {
  printHeader("RFM95 LoRa Send Test (optional: requires LoRa library)");
  Serial.println("If you have the 'LoRa' library by Sandeep Mistry installed and pins mapped correctly, uncomment the include and LoRa init lines in the code.");
  Serial.println("This function will attempt to initialize LoRa and transmit a few test packets. Measure with your spectrum analyzer.");
  // Example instructions (not executed unless you enable LoRa library):
  Serial.println(" -> If you want this to run, uncomment the LoRa include at top and the LoRa init below, then re-upload.");
  
  //Once LoRa.h is enabled:
  LoRa.setPins(PIN_RFM95_NSS, PIN_RFM95_RESET, PIN_RFM95_DIO0);
  if (!LoRa.begin(868E6)) {
    Serial.println("LoRa.begin failed - check IRQ pin and NSS pin mapping (and avoid GPIO6/7).");
    return;
  }
  Serial.println("LoRa initialized. Sending 10 packets (one per second). Use spectrum analyzer to see transmissions.");
  for (int i=0;i<10;i++){
    String payload = "UTest packet #" + String(i);
    LoRa.beginPacket();
    LoRa.print(payload);
    LoRa.endPacket();
    Serial.printf("Sent packet %d\n", i);
    delay(1000);
  }
  Serial.println("Packets sent.");
  
}

/////////////////////////
// Run full sequence
/////////////////////////

void run_all_tests() {
  Serial.println();
  Serial.println("==============================================");
  Serial.println("Starting automated unit test sequence...");
  Serial.println("Observe Serial output for PASS/FAIL and take external measurements as indicated.");
  Serial.println("==============================================");

  test_boot_and_power();
  test_gpio();

  test_wifi_scan();
  test_wifi_softap();

  test_ble_advertise_and_scan();

  // GPS
  test_gps_uart();
  test_gps_i2c_probe();

  // RFM95
  test_rfm95_spi_basic();
  test_rfm95_sendpackets_if_lora_lib();

  Serial.println();
  Serial.println("All tests executed. Inspect output above.");
  Serial.println("For RFM95 TX spectral tests: send LoRa packets (see optional LoRa block) while you measure with your Rigol SA.");
}

void setup() {
  Serial.begin(115200);
  while (!Serial) { yield(); } // wait for serial
  Serial.println("\nESP32 Unit Test Suite starting...");
  // set GPS I2C pins before using Wire
  // Wire.begin(GPS_I2C_SDA, GPS_I2C_SCL); // done in probe
  // Setup LED pin
  pinMode(LED_TEST_PIN, OUTPUT);
  digitalWrite(LED_TEST_PIN, LOW);

  // Small startup delay
  pauseMs(2000);

  run_all_tests();
}

void loop() {
  // Idle. Tests are one-shot at boot; you can expand this loop to re-run tests on demand.
  delay(10000);
}
